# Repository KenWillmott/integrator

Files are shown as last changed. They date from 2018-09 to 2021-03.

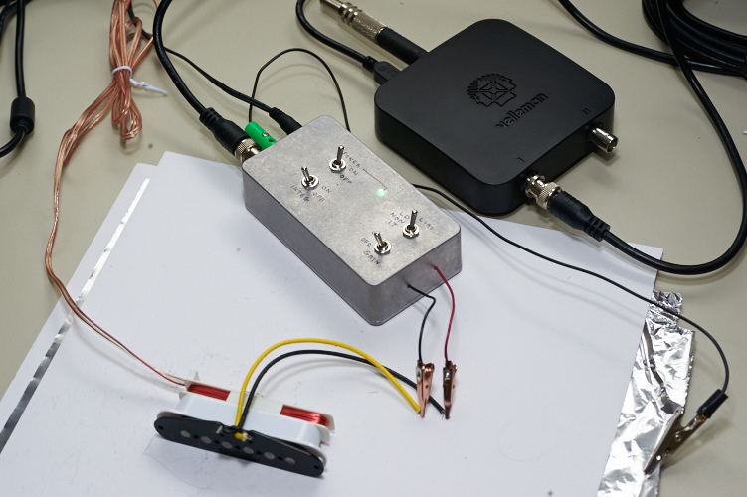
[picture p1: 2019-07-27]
CIN_1659.jpg

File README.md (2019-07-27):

# integrator
Guitar pickup test instrument

The V5.8 integrator circuit provides a high impedance preamplifier, an integrator, and an output amplifier. It also has switches to control input gain, and to select between internally provided test loads. One of the loads is a large capacitor, to measure inductance, and the other is an RC load to simulate a typical guitar circuit. A three way switch can select between these two loads, or neither load in order to make an unloaded (actually minimally loaded) measurement.

For more details, read the wiki:
https://github.com/KenWillmott/integrator/wiki

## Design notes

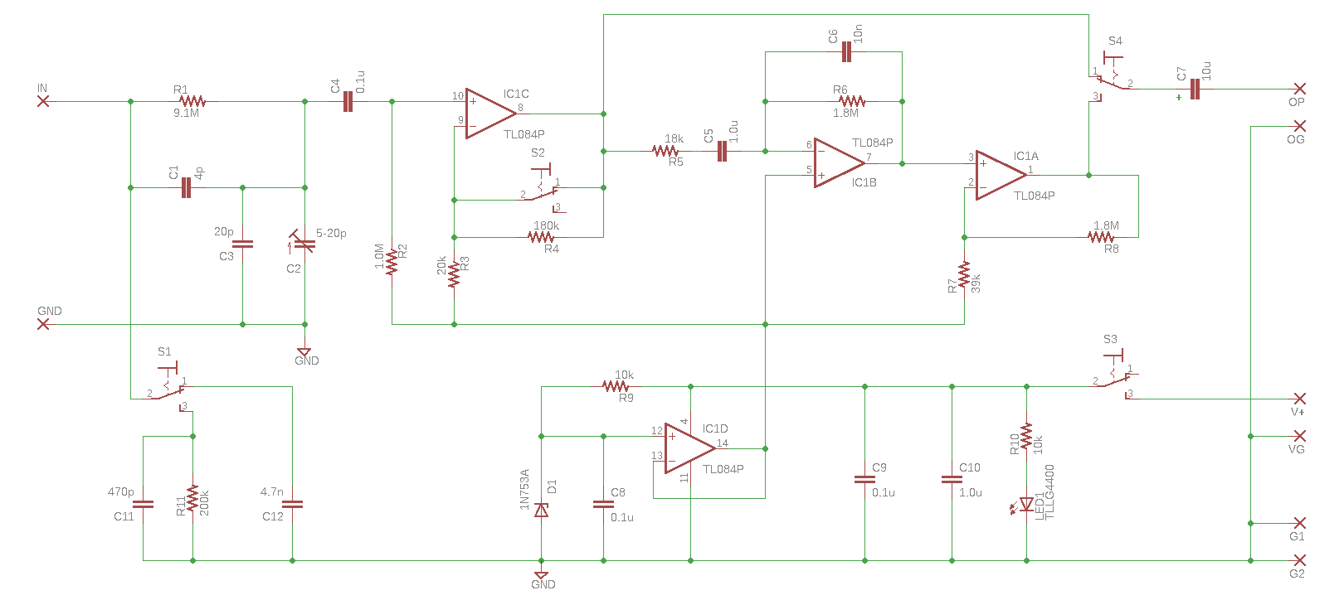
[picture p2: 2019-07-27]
board_V5.8-schematic.png

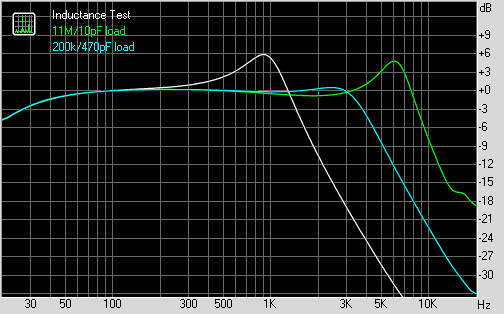
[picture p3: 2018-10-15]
Spectrum.png

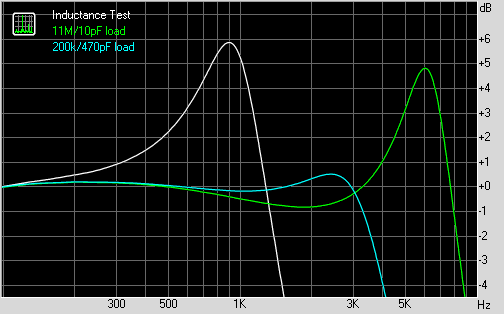
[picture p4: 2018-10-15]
Spectrum_detail.png

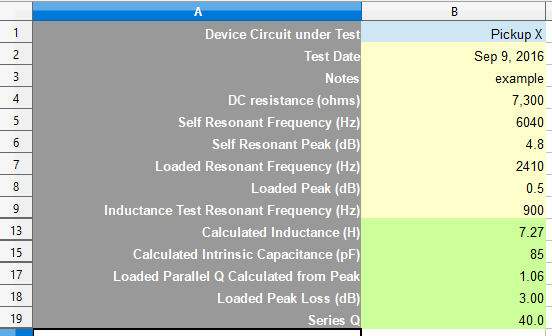
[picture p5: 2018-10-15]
spreadsheet.png

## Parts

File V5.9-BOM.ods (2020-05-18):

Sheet: PCB
Designation | Value | Description | Part Markings | Part # | Manufacturer | Supplier | Supplier Part # | Cost per Unit (CAN$) | Notes
IC1 |  | JFET op amp |  | LT1058ACN | Linear Technology | Mouser | 584-LT1058CN#PBF | $11.91 | Substitutes: LT1058CN/OP482/LF347B/TL084
D1 | 6.2V/500mW | Zener diode |  | 1N753A | Central Semiconductor | Mouser | 610-1N753A | $0.59
LED1 |  | LED |  | LTL-4231N | Lite-On | Mouser | 859-LTL-4231N | $0.10 | 3mm
S1 | On-off-on | toggle switch |  | 100SP3T1B1M2QEH | E-switch | Mouser | 612-100-C1121 | $4.06
S2 | On-on | toggle switch |  | 100SP1T1B1M2QEH | E-switch | Mouser | 612-100-A1121 | $3.37
S3 | On-on | toggle switch |  | 100SP1T1B1M2QEH | E-switch | Mouser | 612-100-A1121 | $3.37
S4 | On-on | toggle switch |  | 100SP1T1B1M2QEH | E-switch | Mouser | 612-100-A1121 | $3.37
R2 | 1.0M | 1/4W resistor 5% |  | CFR-25JR-52-1M | Yageo | Mouser | 603-CFR-25JR-52-1M | $0.14
R6 | 1.8M | 1/4W resistor 5% |  | CFR-25JB-52-1M8 | Yageo | Mouser | 603-CFR-25JB-52-1M8 | $0.14
R8 | 1.8M | 1/4W resistor 5% |  | CFR-25JB-52-1M8 | Yageo | Mouser | 603-CFR-25JB-52-1M8 | $0.14
R9 | 10k | 1/4W resistor 5% |  | CFR-25JB-52-10K | Yageo | Mouser | 603-CFR-25JB-52-10K | $0.14
R10 | 10k | 1/4W resistor 5% |  | CFR-25JB-52-10K | Yageo | Mouser | 603-CFR-25JR-52-10K | $0.14
R1 | 9.1M | 1/4W resistor 5% |  | CFR-25JB-52-9M1 | Yageo | Mouser | 603-CFR-25JB-52-9M1 | $0.14
R4 | 180k | 1/4W resistor 5% |  | CFR-25JB-52-180K | Yageo | Mouser | 603-CFR-25JB-52-180K | $0.14
R5 | 18k | 1/4W resistor 5% |  | CFS1/4CT52R183J | Koa Speer | Mouser | 660-CFS1/4CT52R183J | $0.24
R11 | 200k | 1/4W resistor 5% |  | CFR-25JB-52-200K | Yageo | Mouser | 603-CFR-25JB-52-200K | $0.14
R3 | 20k | 1/4W resistor 5% |  | CFR-25JB-52-20K | Yageo | Mouser | 603-CFR-25JB-52-20K | $0.14
R7 | 39k | 1/4W resistor 5% |  | CFR-25JR-52-39K | Yageo | Mouser | 603-CFR-25JR-52-39K | $0.14
C6 | 10n | MLCC capacitor | 103 | SR155C103JAA | AVX | Mouser | 581-SR155C103JAA | $0.65 | 50V 5%
C4 | 0.1u | MLCC capacitor | 104 | SR215C104JARTR1 | AVX | Mouser | 581-SR215C104JARTR1 | $0.47 | 50V 5%
C8 | 0.1u | MLCC capacitor | 104 | SR215C104JARTR1 | AVX | Mouser | 581-SR215C104JARTR1 | $0.47 | 50V 5%
C9 | 0.1u | MLCC capacitor | 104 | SR215C104JARTR1 | AVX | Mouser | 581-SR215C104JARTR1 | $0.47 | 50V 5%
C5 | 1u | MLCC capacitor | 105 | C330C105J5R5TA | Kemet | Mouser | 80-C330C105J5R | $2.32 | 50V 5%
C7 | 10u | MLCC capacitor | 106 | SR655C106KARTR1 | AVX | Mouser | 581-SR655C106KARTR1 | $6.01 | 50V 5%
C10 | 10u | MLCC capacitor | 106 | C330C105J5R5TA | Kemet | Mouser | 80-C330C105J5R | $2.32 | 50V 5%
C3 | 20p | MLCC capacitor | 200 | SR211A200JAR | AVX | Mouser | 581-SR211A200JAR | $0.51 | 100V 5%
C11 | 470p | MLCC capacitor | 471 | SR215A471JARTR1 | AVX | Mouser | 581-SR215A471JARTR1 | $0.44 | 50V 5%
C12 | 4.7n | MLCC capacitor | 472 | SR215C472JARTR1 | AVX | Mouser | 581-SR215C472JARTR1 | $0.47 | 50V 5%
C1 | 4p | MLCC capacitor | 4 | RDE5C1H4R0C0S1H03A | Murata | Mouser | 81-RDE5C1H4R0C0S1H3A | $0.50 | 50V
C2 | 5-20p | trimmer capacitor |  | GKG20015 | Sprague-Goodman | Mouser | 659-GKG20015 | $6.07 | 6mm
 |  |  |  |  |  |  | (total CAN$) | $49.11

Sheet: Unit
Description | Part # | Manufacturer | Supplier | Supplier Part # | Cost per Unit (CAN$) | Notes
Housing | 1590B | Hammond | Mouser | 546-1590B | $10.36 | Use 1590BBK/Mouser 546-1590B-BK for black housing
DC jack |  |  |  |  |  | 2.1mm DC power jack
banana jack |  |  |  |  |  | small jack for auxiliary ground
BNC panel jack |  |  |  |  |  | for signal output

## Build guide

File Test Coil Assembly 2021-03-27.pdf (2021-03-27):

# Pickup Test Coil Assembly

## Ken Willmott 2021-03

Description
This coil is used to induce a signal in a guitar pickup for the purposes of measuring the pickup frequency response characteristics. It is designed to be driven by a signal generator or audio interface headphone output, and placed in close proximity to the pickup face in order to induce a signal in the pickup by magnetic induction. The magnetic field that the coil produces emulates the time varying magnetic field that the guitar strings produce when they vibrate in front of the pickup.
This is the most common type of pickup test coil, where the test field encompasses the entire pickup. It is also possible to use smaller coils in order to measure a smaller area of the pickup assembly. Experiments have shown that, when used properly, it has minimal effect on the pickup’s response due to its proximity to the pickup’s electromagnetic circuits.
Guitar pickups work by magnetic induction of electrical currents in the pickup coil when a time varying magnetic field is applied (normally, from the strings). This means that every pickup follows, at least closely, Faraday’s Law of Induction which results in the output signal increasing by 6dB/octave or 20dB/decade as the frequency increases. This is the natural mode of signal production in an electric guitar, and produces its characteristic sound.
However, this aggregate response is not ideal for analysis of the important pickup characteristics that derive from the electrical response of the pickup components alone. For this reason, an integrator circuit is normally also required to apply an inverse response of -6db/octave or -20dB/decade, to compensate for the increasing slope produced by magnetic induction. The V5.9 integrator device can be used for this purpose. Some testing can be performed using only a test coil, with the pickup connected to an audio test device through a resistor network.
To produce an accurate plot of output versus frequency, the magnetic field intensity must be constant regardless of frequency. The magnetic field intensity of a coil is proportional to applied current. Since the coil is an inductor electrically, a constant applied voltage would not produce a uniform current at different frequencies. So, it is necessary to incorporate some kind of current regulation in the coil, since the signal generator is generally a voltage source. A series resistance will work for this, if the reactive impedance of the coil is much smaller than its resistance at the highest test frequency used. It is helpful to keep the coil inductance value low in order to achieve this. Most signal generators and also headphone outputs already have an internal resistance that can provide this function if the coil inductance is low enough, thus it may be possible to connect a coil directly. However, I include a 100 ohm resistor in the circuit to ensure that there is an adequate margin regardless of what device is driving the coil.

Specifications

Parameter | Value | Units
Typical drive level | 1 | Vrms
Maximum drive level | 5 | Vrms
Coil inductance | 100 | uH
DC resistance | 100 | ohms

Materials
- Humbucker bobbin
- AWG# 30 magnet wire
- 1-7/8” Kapton tape
- 1/2” Kapton tape
- 36” AWG# 26 stranded insulated 2 conductor wire
- 100 ohm 1/2W axial lead resistor
- 3/4” heat shrink tubing

Tools
- Wire cutter
- Soldering iron
- 1/16” drill bit
- hand drill or drill press

Procedure
Follow the steps illustrated in the following images. The coil winding itself is not shown, but it consists of securing the bobbin to a handle or bench jig, and applying turns by hand. A motorized method could be used but the turns can be applied by hand in just a few minutes.
Pay attention to soldering technique, ensure that there are no shorts or cold solder joints. The side opposite to the side that carries the components, should be kept as flat as possible when the tape is wrapped around the bobbin. That is so it will remain in a fixed, stable position when it is used on the top of a single coil type pickup.

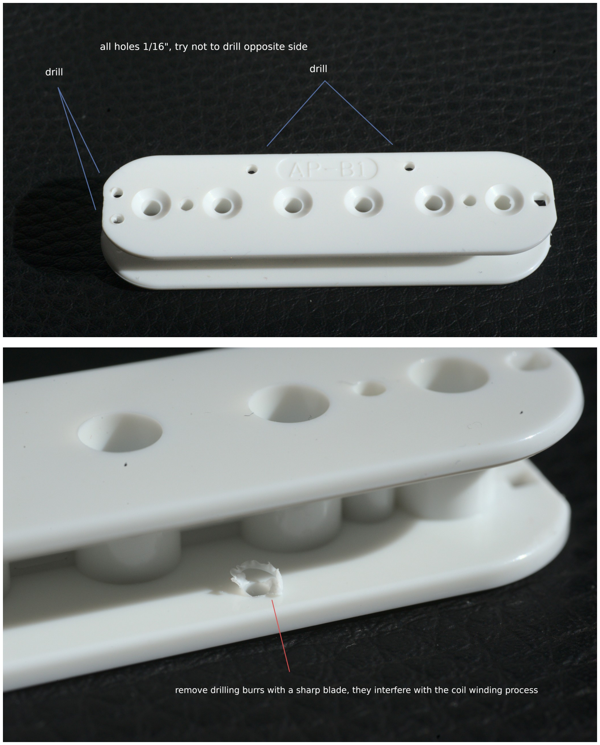
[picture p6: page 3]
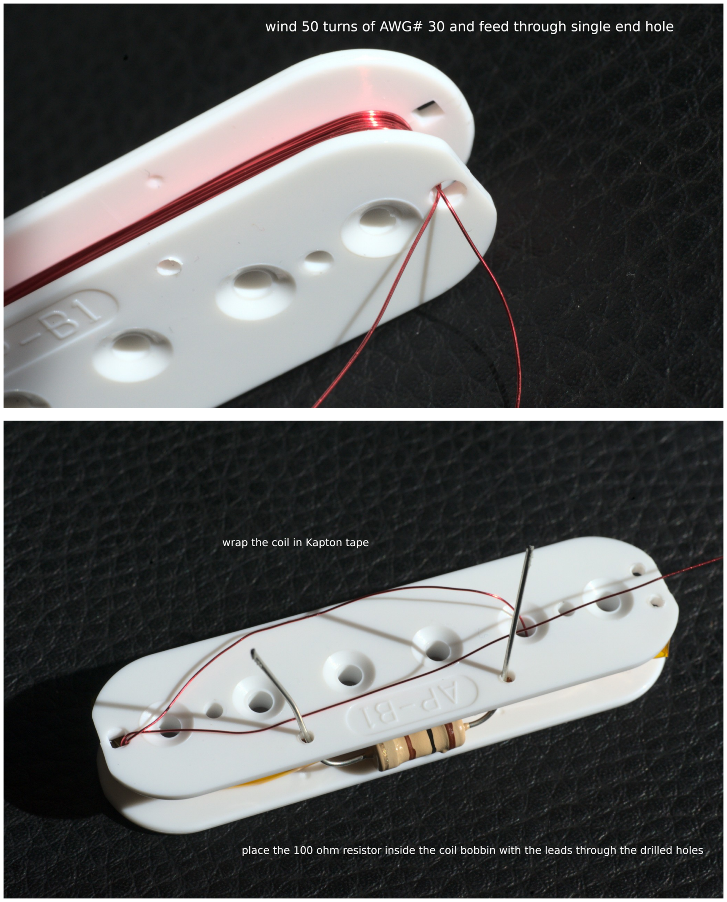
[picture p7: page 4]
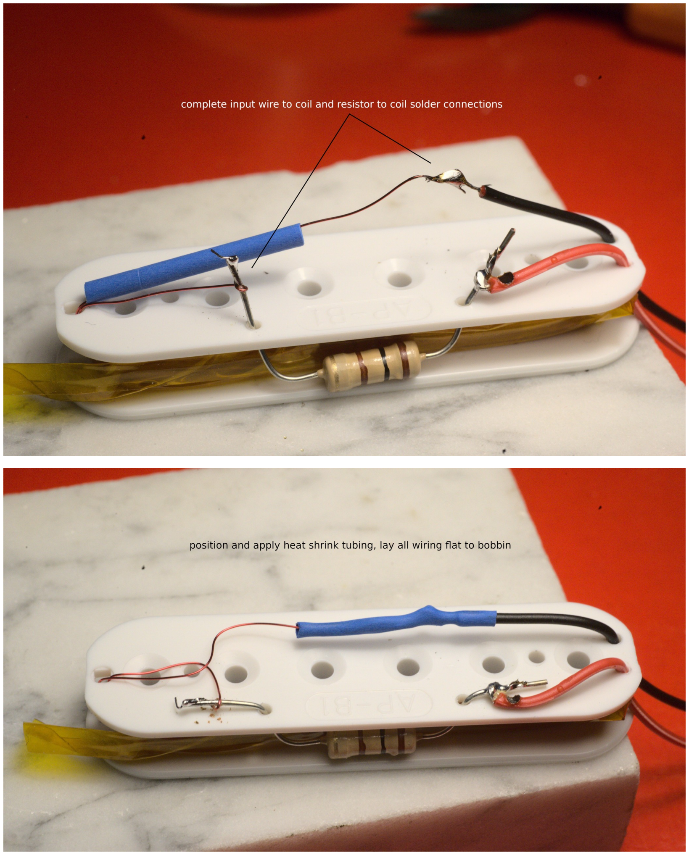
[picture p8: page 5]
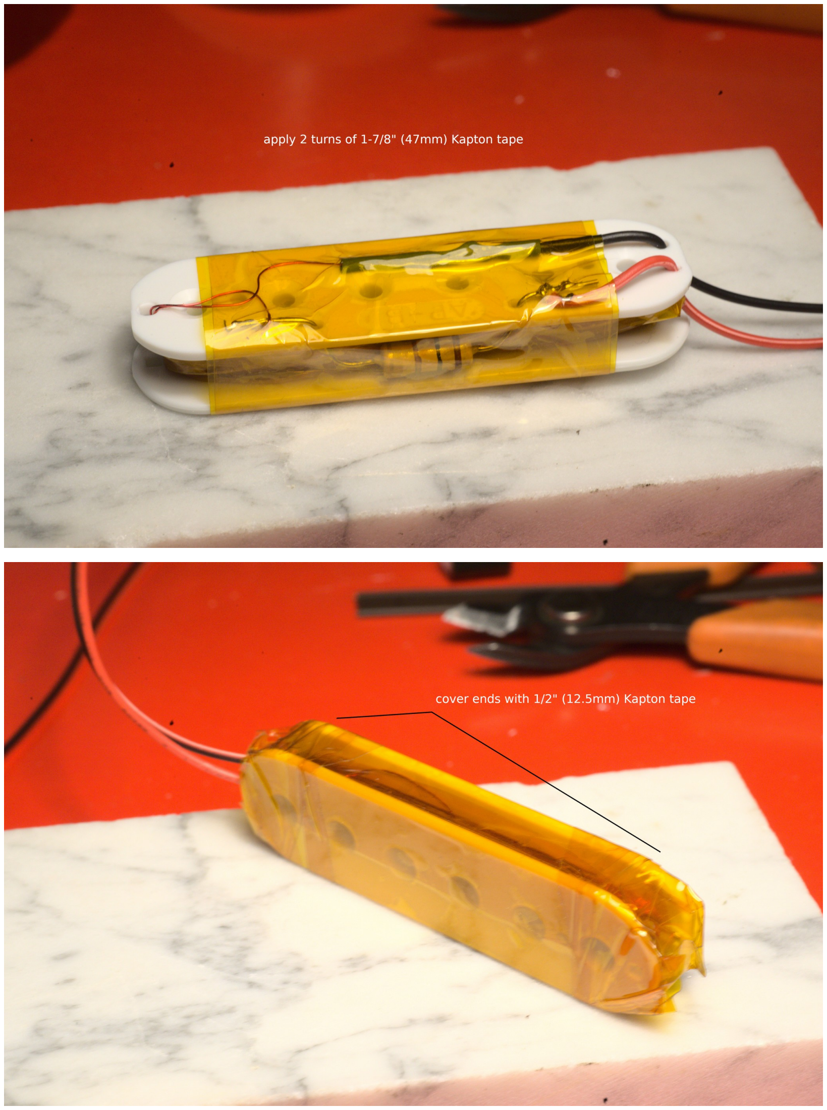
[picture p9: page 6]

References
https://github.com/KenWillmott/integrator/wiki

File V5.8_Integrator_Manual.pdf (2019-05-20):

# V5.8 Integrator Manual

This document explains how to produce the Bode plots for an electromagnetic guitar pickup using the V5.8 Integrator.

Equipment:

- Test coil – 50-100 turns of 26 AWG coated copper magnet wire on a non-magnetic bobbin such as plastic or wood.
- V5.8 integrator board
- Either one of these:
1. computer audio interface such as the Scarlett Focusrite 2i2 or equivalent
2. software oscilloscope
- RightMark audio test software or equivalent

Overview:

The test setup consists of an audio signal loop, where signals produced by the test software suite are sent from the output of the computer interface device, to the test coil. The field from the test coil induces a voltage in the pickup, which is connected to the input of the integrator. The integrator output is connected to the input of the audio device, where it is converted to digital format and returned to the audio test software suite for recording and analysis.

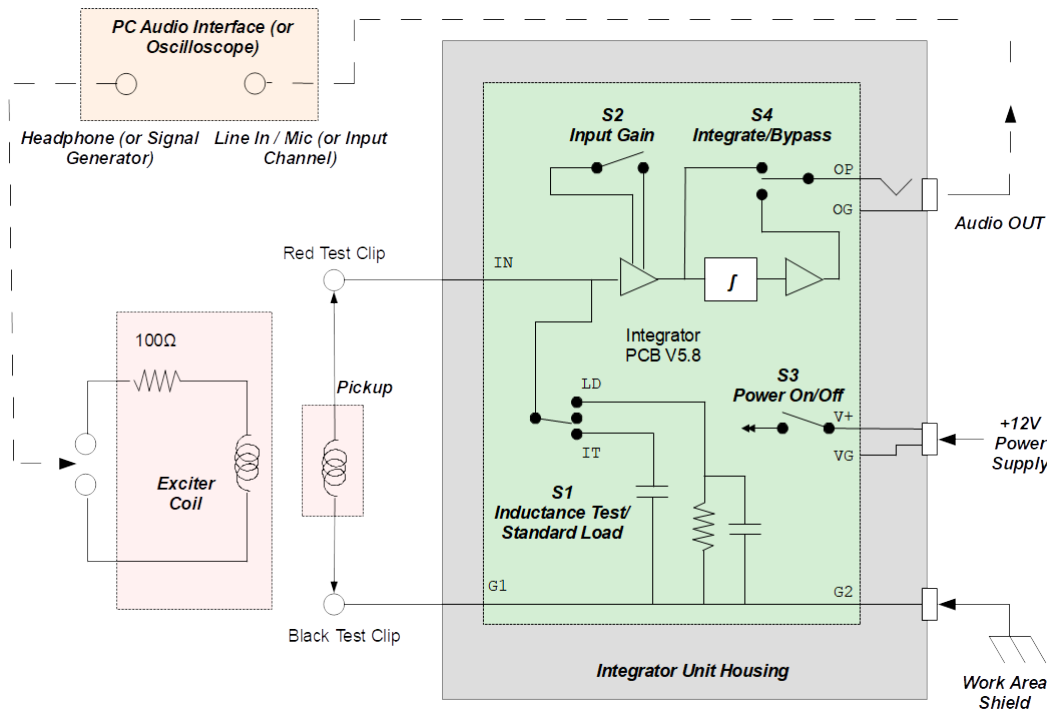
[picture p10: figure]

Here is a photograph of a typical test bench layout:

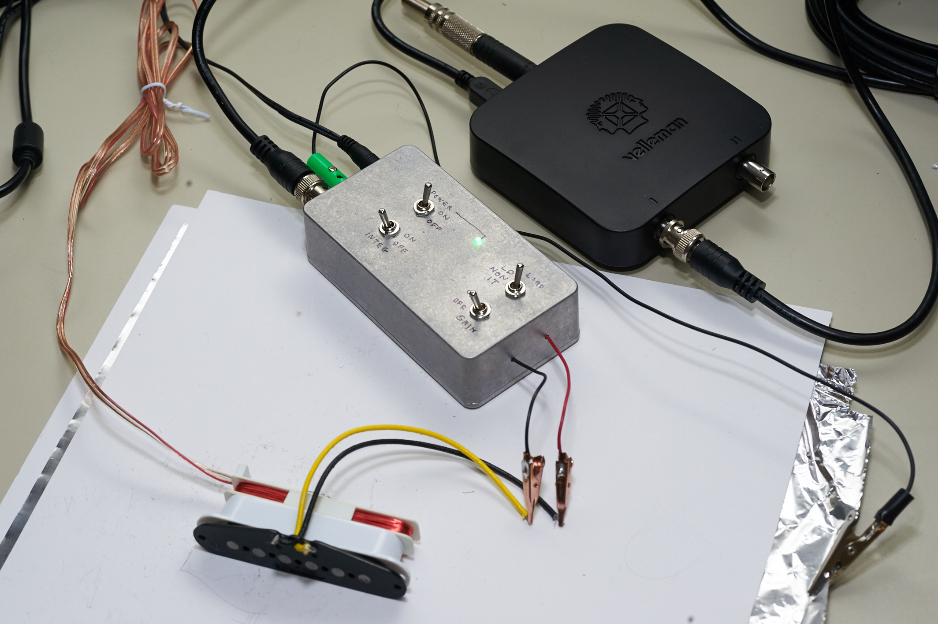
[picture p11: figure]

The V5.8 integrator circuit provides a high impedance preamplifier, an integrator, and an output amplifier. It also has terminals for switches to control input gain, and to select between internally provided test loads. One of the loads is a relatively large capacitor, to measure inductance, and the other is an RC load to simulate a typical guitar circuit. A three way switch can select between these two loads, or neither load in order to make an unloaded (actually minimally loaded) measurement. An auxiliary ground wire connects to a workbench shield (not shown). In the photo above, it is a large piece of aluminum foil underneath the paper surface that supports the test apparatus. This is for hum reduction.

To prepare for the test, the test coil must be placed against the pickup housing. The leads are connected to the integrator input. If the pickup is shielded, the shield connection should also be connected to the input ground (black). Connecting IN to the shield will result in bad measurements. Otherwise the polarity does not matter. Ensure that 12V power is applied to the integrator and that connections to and from the computer interface are complete. Launch the software suite and configure the sound interface options, select the option to perform Bode plots, and any other settings that are permanently required. Ensure that any monitor loopback setting in the audio device is disabled.

Procedure:

Launch the analysis software suite. For RightMark, you can click on a "Run Tests" button. It will show you the following display, if no pickup is connected:

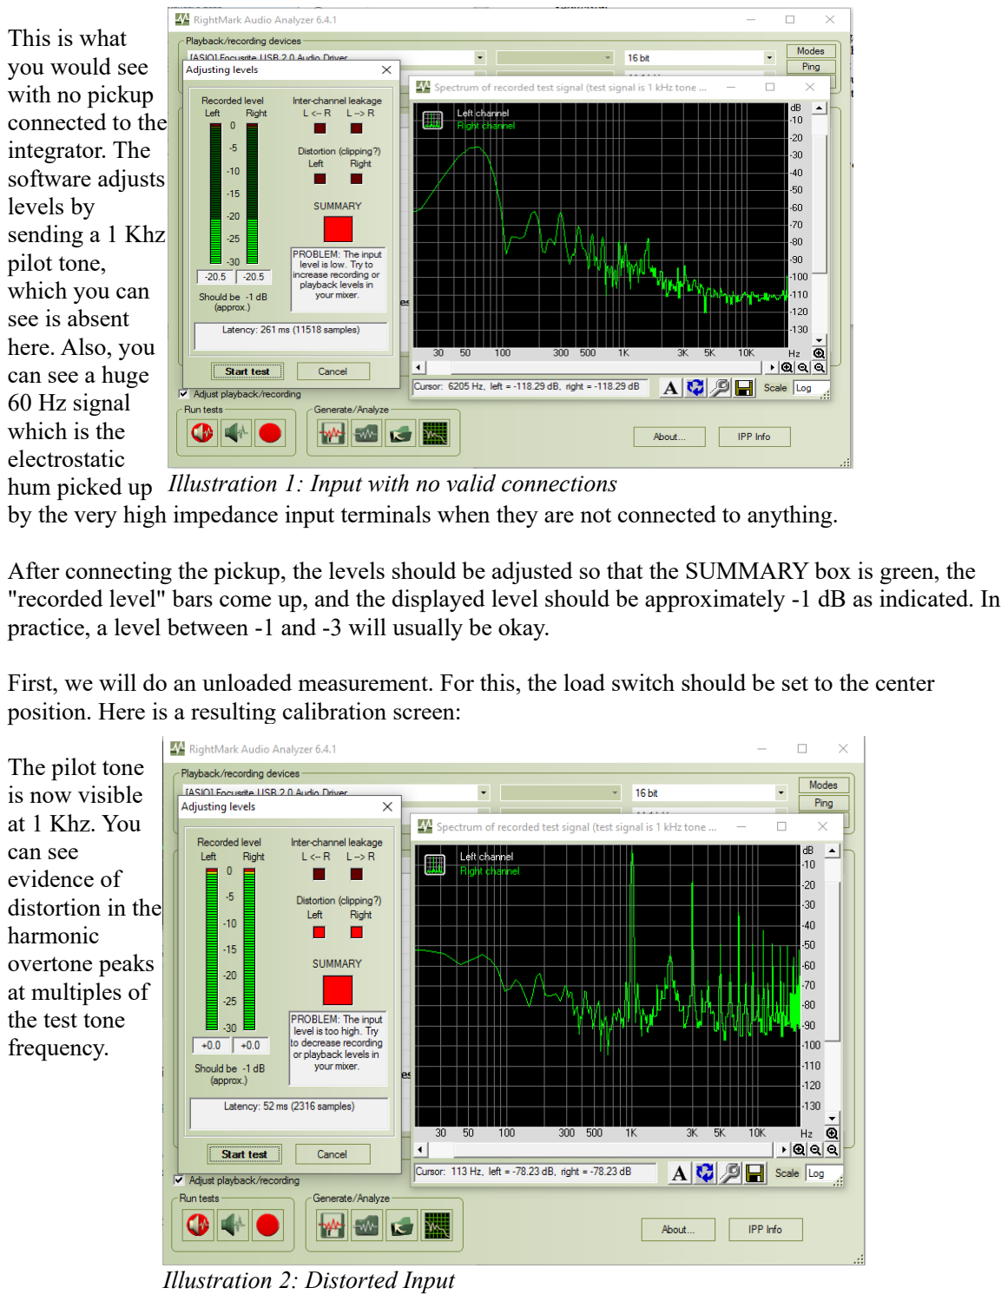
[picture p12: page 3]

This is what
you would see
with no pickup
connected to the
integrator. The
software adjusts
levels by
sending a 1 Khz
pilot tone,
which you can
see is absent
here. Also, you
can see a huge
60 Hz signal
which is the
electrostatic
hum picked up
by the very high impedance input terminals when they are not connected to anything.

After connecting the pickup, the levels should be adjusted so that the SUMMARY box is green, the "recorded level" bars come up, and the displayed level should be approximately -1 dB as indicated. In practice, a level between -1 and -3 will usually be okay.

First, we will do an unloaded measurement. For this, the load switch should be set to the center position. Here is a resulting calibration screen:

The pilot tone
is now visible
at 1 Khz. You
can see
evidence of
distortion in the
harmonic
overtone peaks
at multiples of
the test tone
frequency.

Illustration 1: Input with no valid connections

Illustration 2: Distorted Input

To obtain the best signal to noise, it is good to increase the drive to the test coil as much as possible, and then adjust the audio interface input level until the right level is attained, and there is not too much distortion or 60 Hz interference as it appears in the previous two illustrations. As a rule of thumb, neither the distortion products, nor the hum, should exceed -50 dB or so. It is possible to run tests with greater than this, but the accuracy will be impaired.

Here is a good calibration screen, when you see this you can press the "Start Test" button:

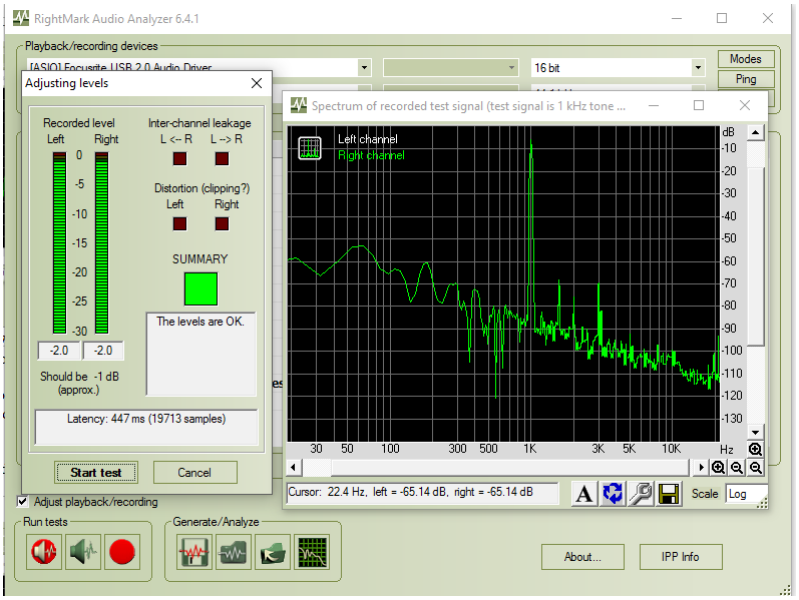
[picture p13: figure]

When the frequency sweep is completed, you will be prompted to save the plot. It is a good idea to name it at this point by typing in the name field. In this case, I'm calling it "No load".

Illustration 3: Typical acceptable calibration screen

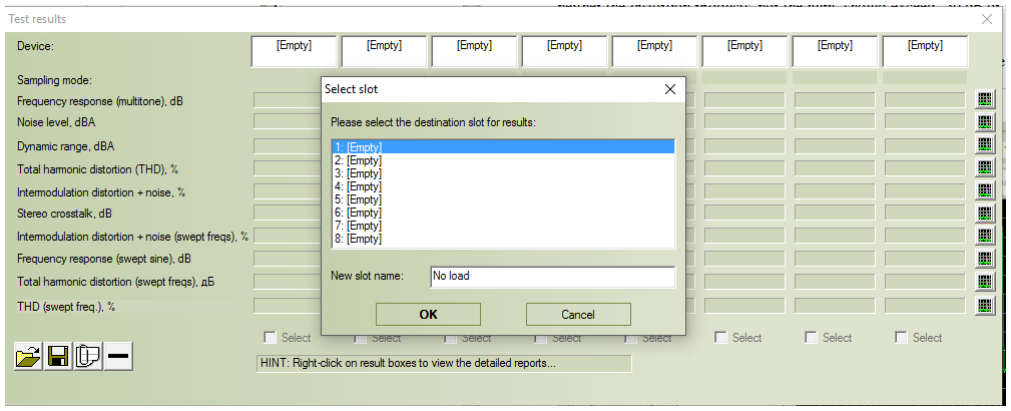
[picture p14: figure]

Click on "OK". Now your first sweep will be recorded in the first of 8 possible slots:

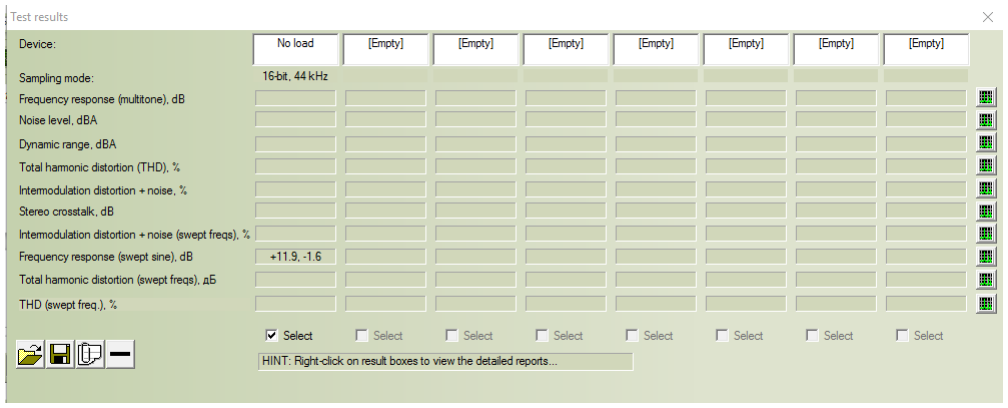
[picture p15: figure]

Move the load select switch on the integrator to the "test load" position. Click again on the "Run Tests" button. Adjust the levels as before, and complete another sweep. You will again be prompted and you can name this sweep "loaded" for example (You can also include the pickup name or any data you want to appear on the final plot).

Finally, Move the load select switch on the integrator to the "Inductance test" position. Click again on the "Run Tests" button. After running and naming the sweeps, you will now have three sweeps stored:

Illustration 4: Name the slot

Illustration 5: First slot

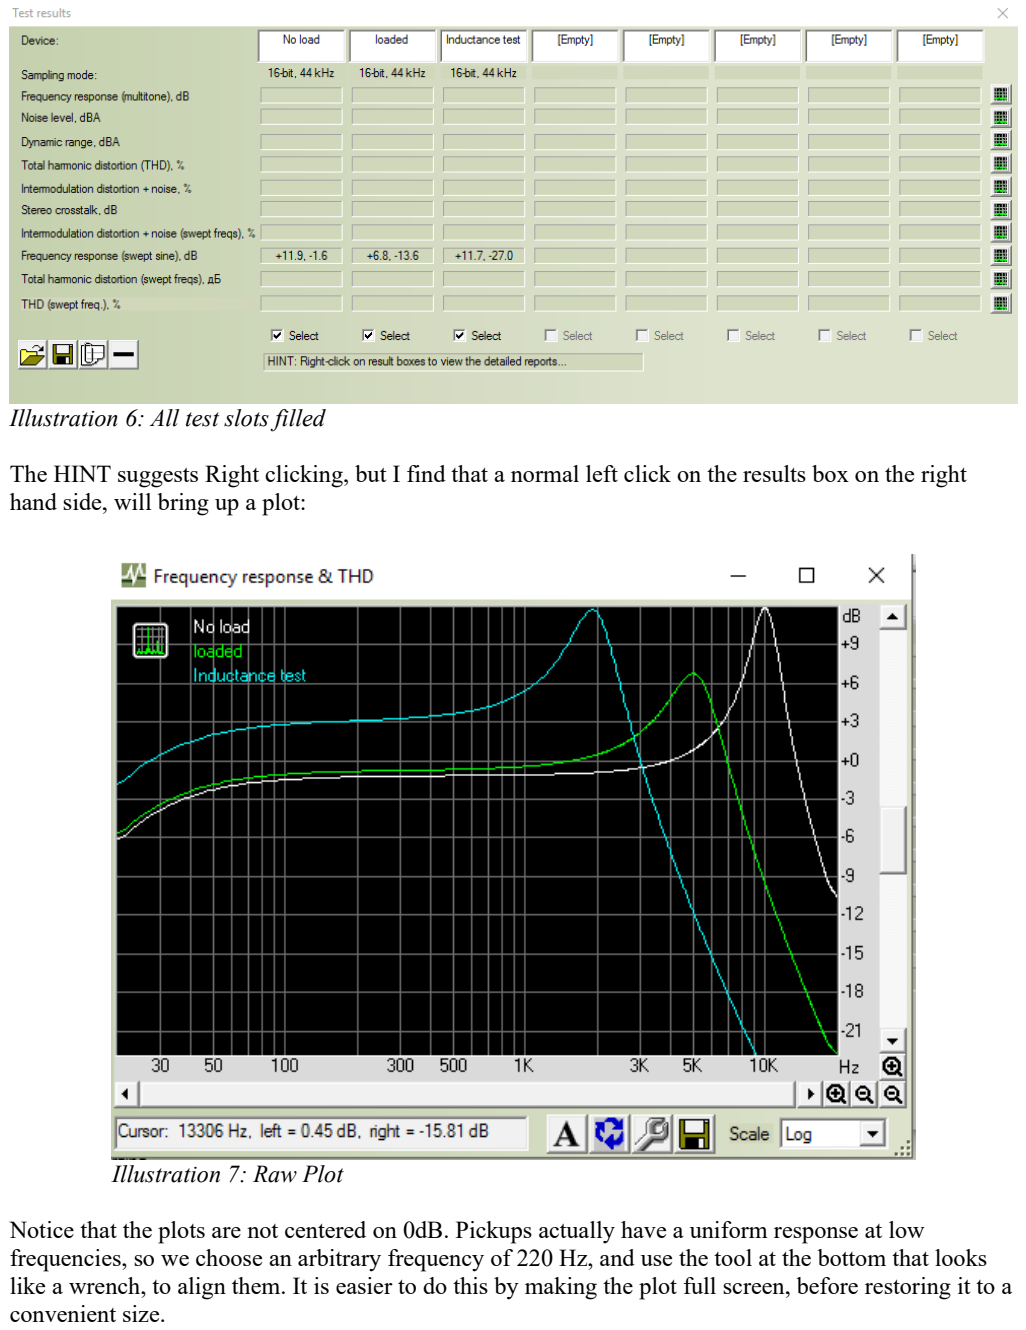
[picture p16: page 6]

The HINT suggests Right clicking, but I find that a normal left click on the results box on the right hand side, will bring up a plot:

Notice that the plots are not centered on 0dB. Pickups actually have a uniform response at low frequencies, so we choose an arbitrary frequency of 220 Hz, and use the tool at the bottom that looks like a wrench, to align them. It is easier to do this by making the plot full screen, before restoring it to a convenient size.

Illustration 6: All test slots filled

Illustration 7: Raw Plot

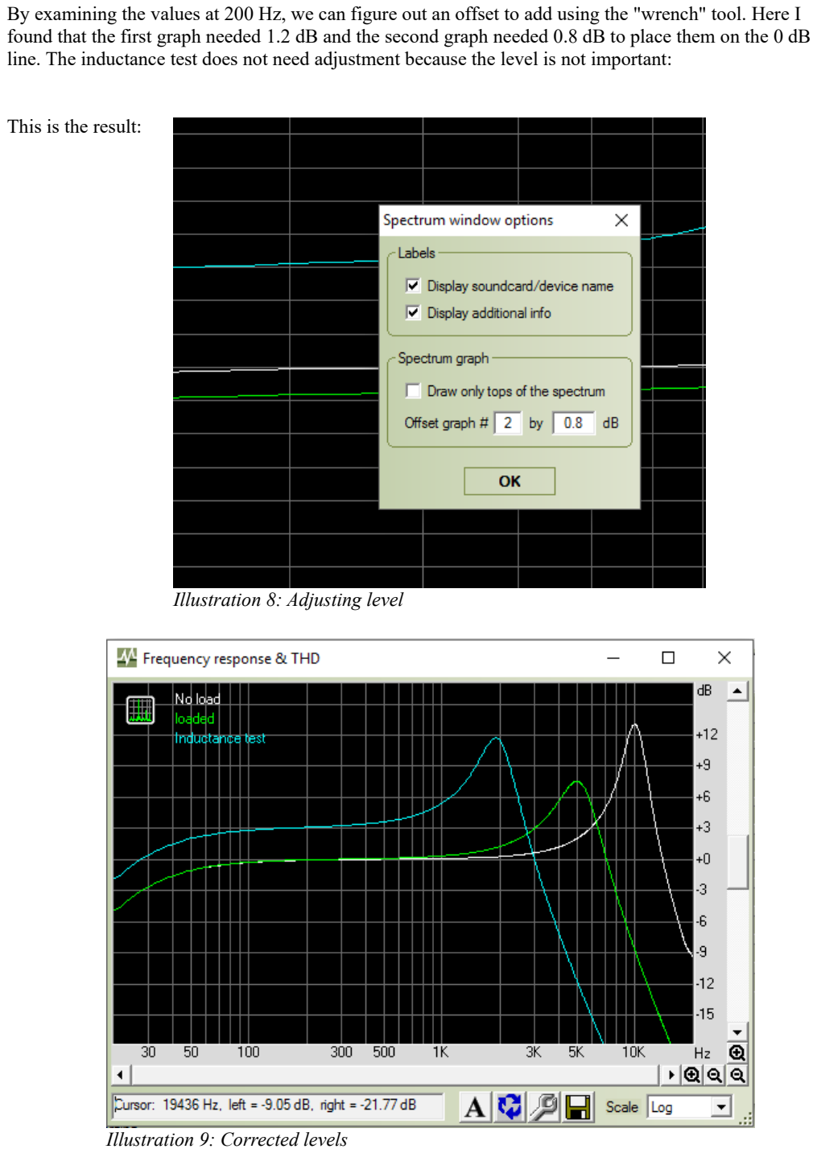
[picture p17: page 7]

By examining the values at 200 Hz, we can figure out an offset to add using the "wrench" tool. Here I found that the first graph needed 1.2 dB and the second graph needed 0.8 dB to place them on the 0 dB line. The inductance test does not need adjustment because the level is not important:

This is the result:

Illustration 8: Adjusting level

Illustration 9: Corrected levels

Now that the levels are corrected, we can use the zoom tools in Rightmark to collect data. Here we place the cursor on the peak of the unloaded measurement, and the frequency is displayed in a text box at the lower left, as well as it being possible to read with reference to the marking grid.

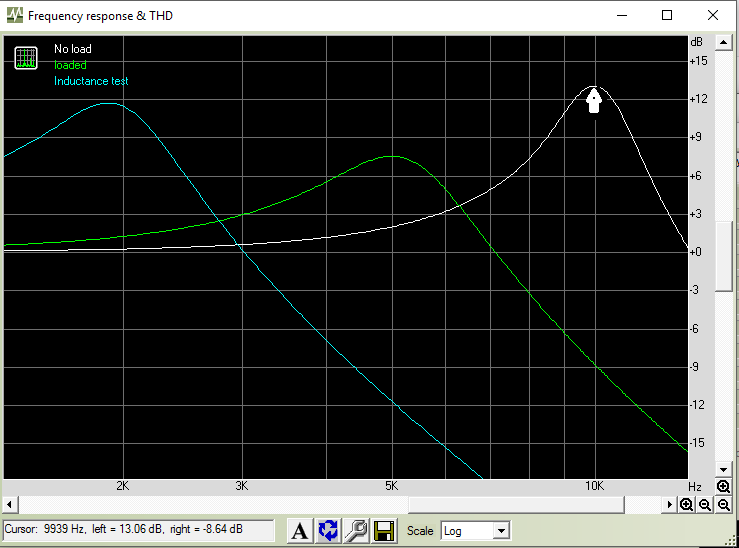
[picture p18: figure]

After the peak amplitude and frequency of the loaded and unloaded plots, and the frequency of the inductance test are recorded, the plots can be selected and scaled in various ways to highlight different aspects or display a useful overall graph. With eight slots available, more than one pickup can be compared with another, or changes in the pickup can be documented. I have found that it is useful to have a spreadsheet that can be used to enter the data that is produced by the plots, and automatically calculates key values, such as the inductance.

Illustration 10: Capturing measurement data

## Input Frequency Response Calibration

The input circuit consists of an RC voltage divider, as is used in most oscilliscope probes. Just as with the probes, stray capacitances in the circuit require that the capacitor values be adjusted to achieve a flat frequency response. Probes have an adjustable capacitor to allow user adjustment, and this feature is also built into the V5.8 PCB. Consequently, it is good to adjust variable capacitor C2 after constructing a new integrator. This should also be done if the op amp is replaced.
The values of C1 and C2 are chosen somewhat empirically to match the present layout and input capacitance of the LT1058 op amp, which influences the circuit. The 4pF/30pF (V5.6), 4pF/40pF (V5.7) 4pF/25-45pF (V5.8) combination comes quite close, but it isn't perfect. The difference shows up as an inaccuracy in amplitude values as measured here with an arbitrary pickup:

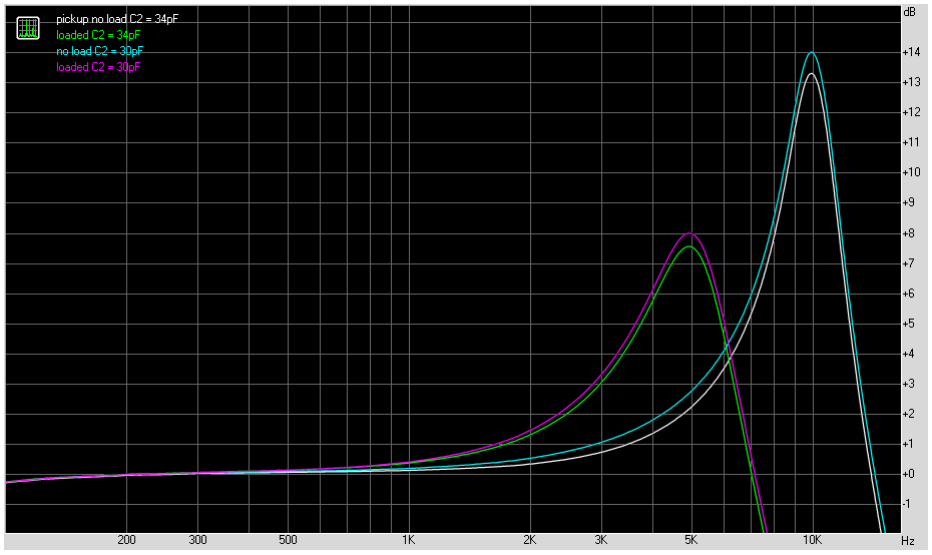
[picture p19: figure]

On an oscilloscope, the frequency response can be monitored by looking at the "squareness" of a test signal while adjusting the probe capacitor. Consequently, this method can also be used when the integrator is used with a software oscilliscope. I found another method so that the calibration can be performed without a scope, using only the integrator circuitry. The key is that the -20dB/decade slope of the integrator is combined with the input circuit slope. So, if the circuit is not balanced, a slighly different slope will be observed. By appying the sweep test generator output directly to the input, it is possible to measure and graph the integrator slope, and adjust the capacitor values until it is closer to the desired -20dB response.

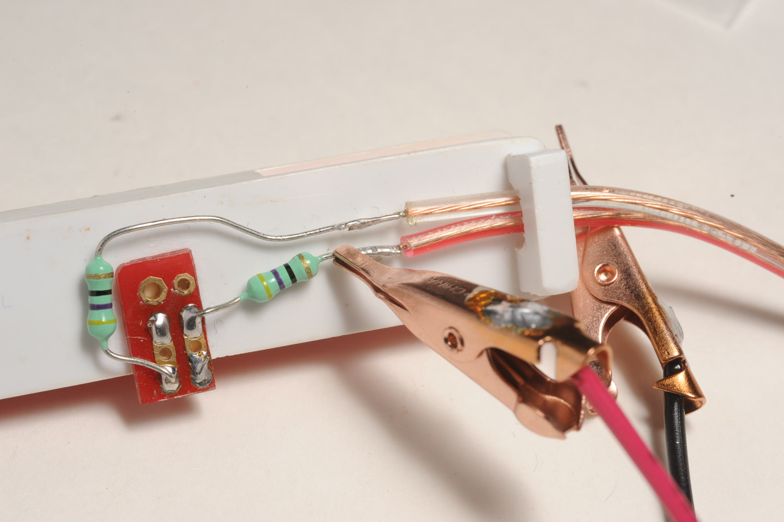
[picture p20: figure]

Since the grounds are usually common on the computer DAC interface, I found that I could just connect the input to the DAC output where it appears on the test coil (before the 100 ohm resistor!).

Running some test sweeps produces a plot that has useful slopes above 200 Hz or so. Below that, the huge gain distorts the curve but we can ignore that. By choosing two values that are a decade apart, the plot should show a -20dB difference. Choose 500 Hz as a low frequency, normalize it to 0dB and then examine the response at 5000 Hz. Adjusting variable capacitor C2 will alter the slope. Thus when the normalized response is exactly -20dB at 5000 Hz, calibration is complete.

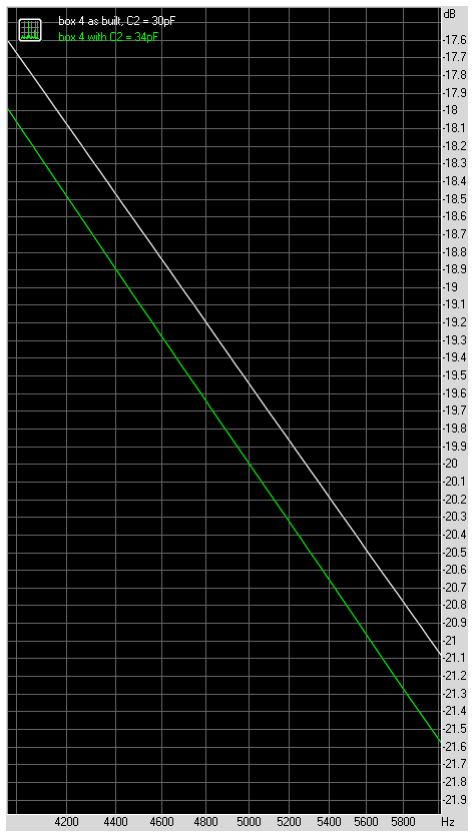
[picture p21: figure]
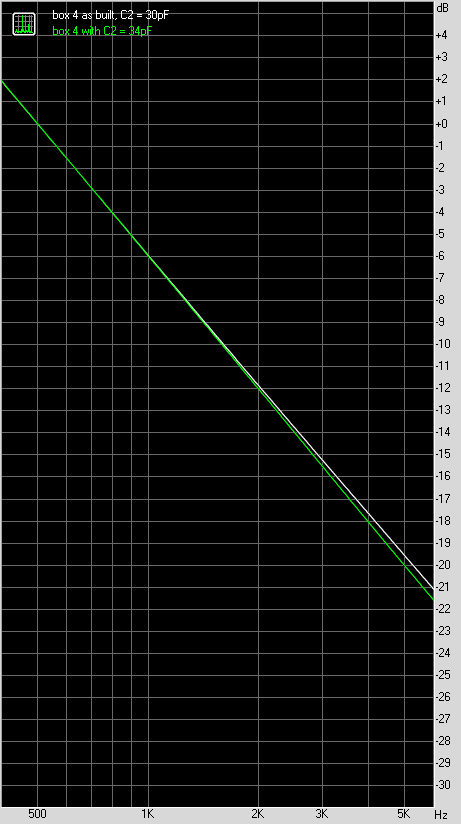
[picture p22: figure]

If an oscilloscope is available, it is much easier to adjust C2 using the traditional squarewave method. Apply an approximately 500Hz square wave from a signal generator, or from the calibration lug of the scope, if it has one, to the input of the integrator. Set the integrator to the "no load" position, Gain switch to +20dB, integration switch to "off". Connect the integrator output to a scope input.
You should see the square wave on the scope display. The leading edge will either overshoot or undershoot, as here:

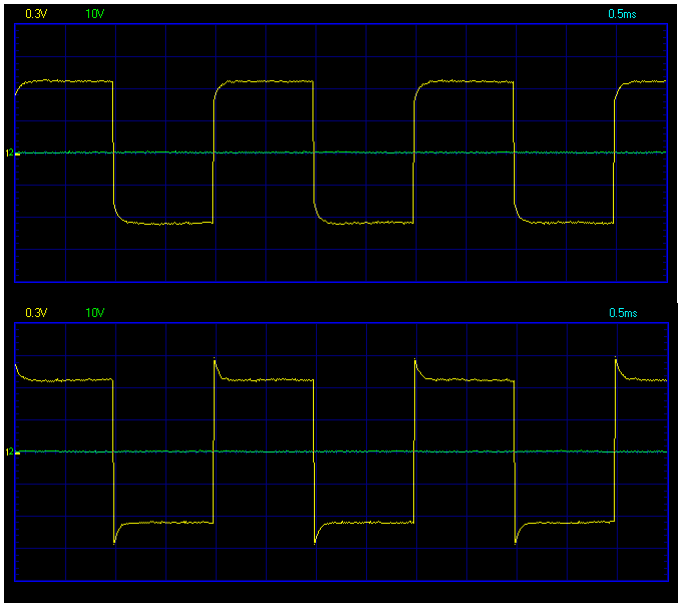
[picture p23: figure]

Simply adjust C2 until there is minimal undershoot/overshoot as below, and calibration is complete:

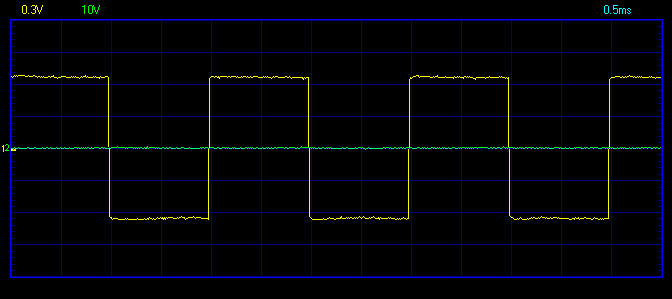
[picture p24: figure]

## Appendix

V5.8 Integrator Schematic:

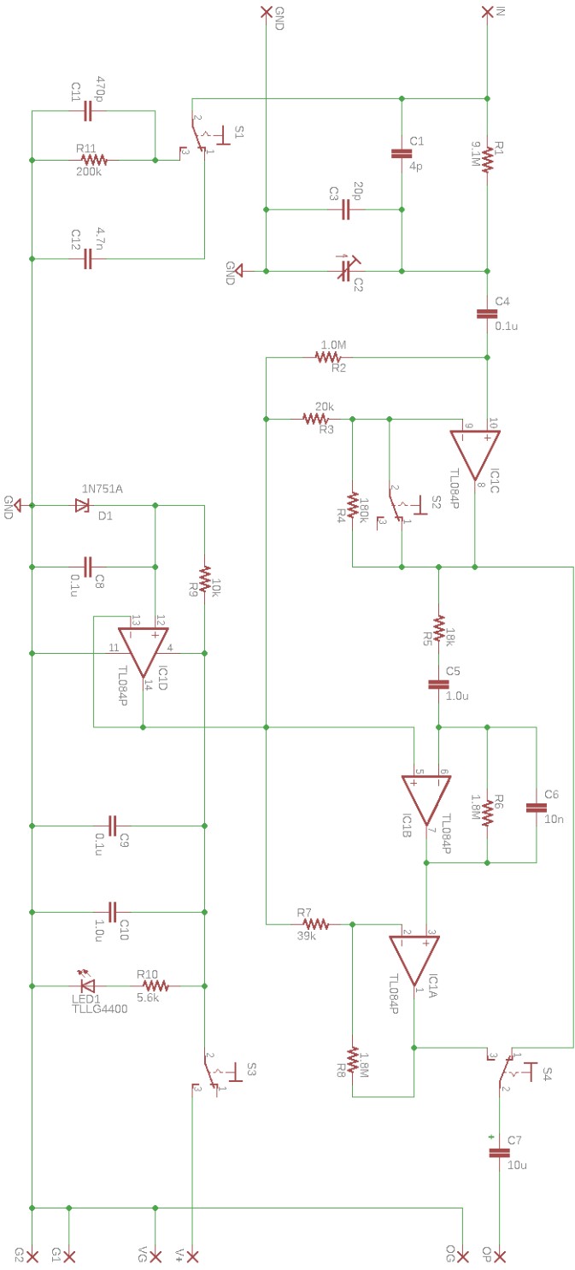
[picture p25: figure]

Note:
The schematic shows IC1 as a TL084P. This part will work, but the preferred part is the Linear Technologies LT1058ACN. The LT part has better GBP, which results in more accurate integrator response at higher frequencies.
The input circuit is sensitive, so the test leads as well as the switch connections LD/COM/IT should be as short as possible. The circuit should be in a shielded enclosure, and the test surface must be grounded. It can be conveniently connected to one of the auxiliary ground points G1/G2 by running an additional wire and clip lead for that purpose, to a banana jack on the enclosure.
Because of the sensitivity of the circuit to small capacitances, the final device calibration should be performed with the entire device fully assembled, in its case. For this reason, I recommend placing C2 on the solder side of the PCB so that it is accessible to a screwdriver with the unit assembled and the enclosure cover removed. However, I have found that the input network is mostly affected by the input components including the op amp, and does not vary significantly enough to worry about, if for some reason this is not possible.

The V5.7 circuit has been upgraded to V5.8. Here is a view of an assembled V5.8 board:

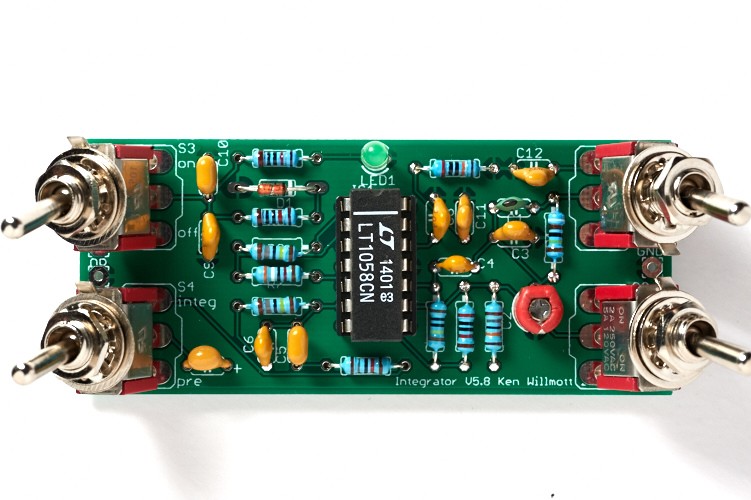
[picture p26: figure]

V5.8 Integrator PCB Parts Layout:

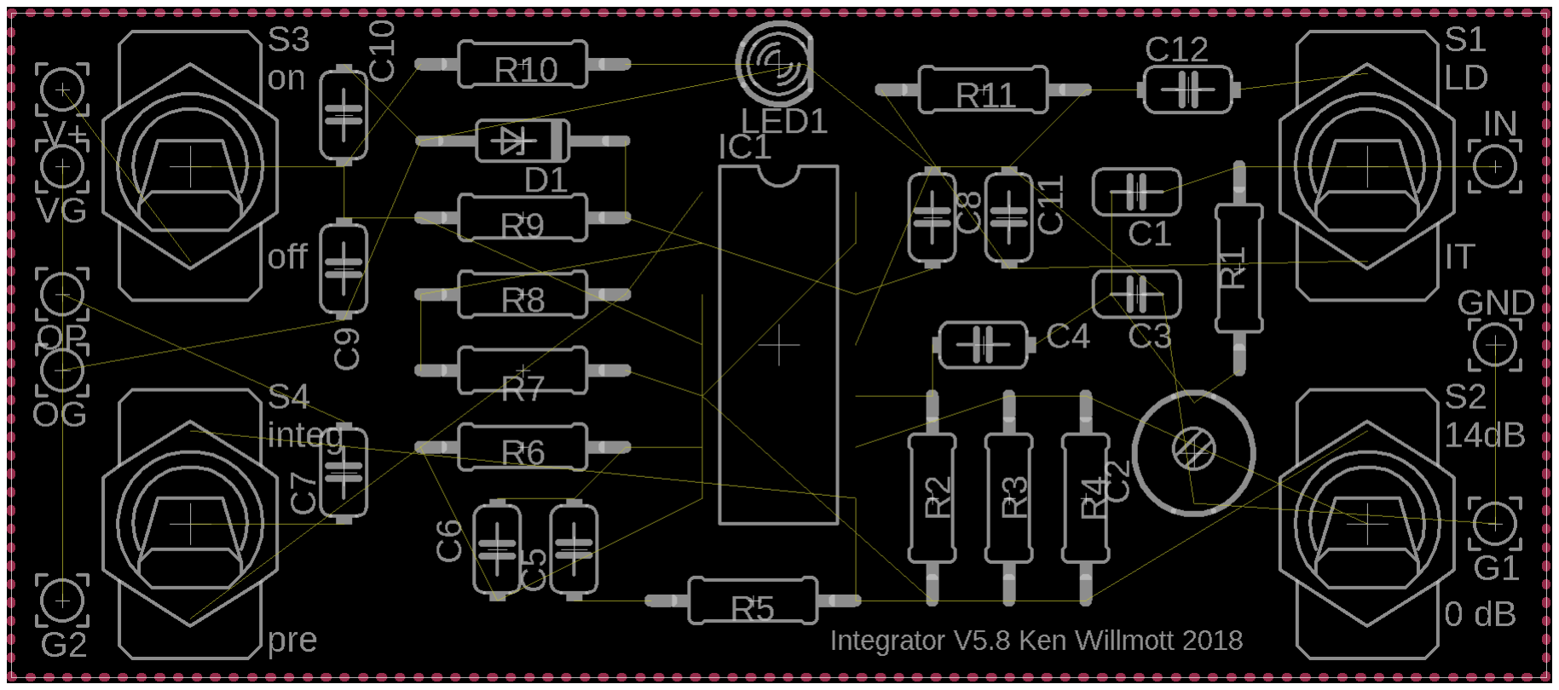
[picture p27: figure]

Here is a recommended enclosure installation:

Notes:

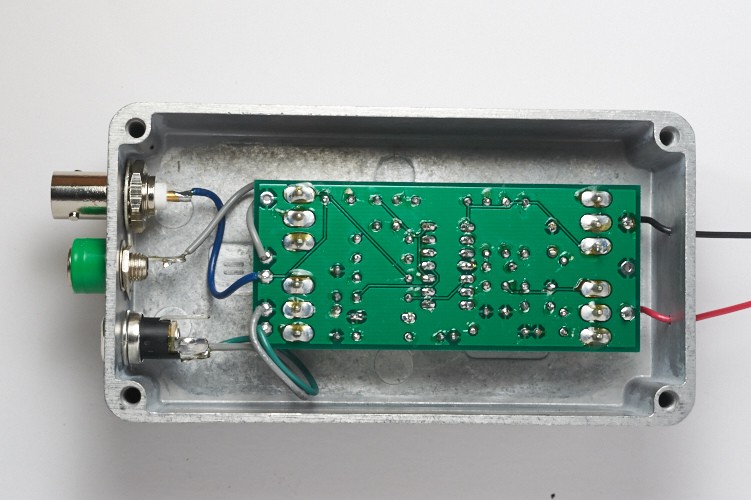
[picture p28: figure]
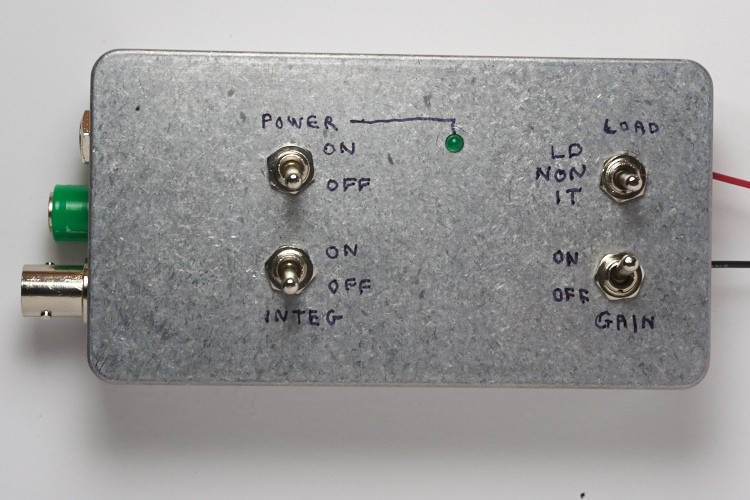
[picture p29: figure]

1. The housing is grounded via the ground connection of the output jack. This can be a BNC or 1/4" phone jack, or any other audio plug. If the jack has no ground connection to the housing, then a separate ground connection must be made to the housing, or the auxiliary ground banana jack may be used for this purpose instead.
2. The auxiliary ground connection does not normally need a wire, because it can be mounted in such a way that the sleeve contacts the housing directly, providing a ground. If needed, it can be wired to G2 on the PCB.
In order to facilitate the alignment of switch mounting holes, it is preferable to assemble the switches into the housing prior to soldering them to the PCB.

© Ken Willmott, 2019

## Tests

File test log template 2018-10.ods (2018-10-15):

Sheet: Test Log
Device Circuit under Test | Test Date | Notes | DC resistance (ohms) | Self Resonant Frequency (Hz) | Self Resonant Peak (dB) | Loaded Resonant Frequency (Hz) | Loaded Peak (dB) | Inductance Test Resonant Frequency (Hz) | Inductance Test Capacitance (F) | Probe Capacitance (pF) | Test Load Resistance (ohms) | Calculated Inductance (H) | Calculated Intrinsic Capacitance (F) | Calculated Intrinsic Capacitance (pF) | Loaded Parallel Q Calculated from Rs, Rl | Loaded Parallel Q Calculated from Peak | Loaded Peak Loss (dB) | Series Q | Calculated Loaded Resonant Frequency (Hz)
Formula template row |  |  |  |  |  |  |  |  | 4.3E-09 | 10.0 | 200,000 | #DIV/0! | #DIV/0! | #DIV/0! | #DIV/0! | 1.00 | #DIV/0! | #DIV/0! | #DIV/0!
Example Test | Sep 9, 2016 | V5.4 box | 7,300 | 6240 | 3 | 2740 | 1.4 | 1100 | 4.3E-09 | 10.0 | 200,000 | 4.87 | 1.24E-10 | 124 | 1.75 | 1.17 | 3.5 | 27.18 | 2961

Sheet: Constants
Test load resistance (ohms) | 200000
Test load capacitance (F) | 4.70E-010
Inductance test load capacitance (F) | 4.3E-09
Test probe capacitance (pF) | 10

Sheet: Results Report
Device Circuit under Test | Example Test
Test Date | Sep 9, 2016
Notes | V5.4 box
DC resistance (ohms) | 7,300
Self Resonant Frequency (Hz) | 6240
Self Resonant Peak (dB) | 3
Loaded Resonant Frequency (Hz) | 2740
Loaded Peak (dB) | 1.4
Inductance Test Resonant Frequency (Hz) | 1100
Inductance Test Capacitance (F) | 4.3E-09
Probe Capacitance (pF) | 10.0
Test Load Resistance (ohms) | 200,000
Calculated Inductance (H) | 4.87
Calculated Intrinsic Capacitance (F) | 1.24E-10
Calculated Intrinsic Capacitance (pF) | 124
Loaded Parallel Q Calculated from Rs, Rl | 2
Loaded Parallel Q Calculated from Peak | 1.17
Loaded Peak Loss (dB) | 3.53
Series Q | 27.2
Calculated Loaded Resonant Frequency (Hz) | 2960.54
Device Circuit under Test | Example Test
Test Date | 42622
Notes | V5.4 box
DC resistance (ohms) | 7300
Self Resonant Frequency (Hz) | 6240
Self Resonant Peak (dB) | 3
Loaded Resonant Frequency (Hz) | 2740
Loaded Peak (dB) | 1.35
Inductance Test Resonant Frequency (Hz) | 1100
Inductance Test Capacitance (F) | 4.3E-09
Probe Capacitance (pF) | 10
Test Load Resistance (ohms) | 200000
Calculated Inductance (H) | 4.86840205854016
Calculated Intrinsic Capacitance (F) | 1.23624054898093E-10
Calculated Intrinsic Capacitance (pF) | 123.624054898093
Loaded Parallel Q Calculated from Rs, Rl | 1.75349222989962
Loaded Parallel Q Calculated from Peak | 1.16815372986132
Loaded Peak Loss (dB) | 3.52807691539466
Series Q | 27.184344568182
Calculated Loaded Resonant Frequency (Hz) | 2960.54159609976
Device Circuit under Test | Example Test
Test Date | 42622
Notes | V5.4 box
DC resistance (ohms) | 7300
Self Resonant Frequency (Hz) | 6240
Self Resonant Peak (dB) | 3
Loaded Resonant Frequency (Hz) | 2740
Loaded Peak (dB) | 1.35
Inductance Test Resonant Frequency (Hz) | 1100
Inductance Test Capacitance (F) | 4.3E-09
Probe Capacitance (pF) | 10
Test Load Resistance (ohms) | 200000
Calculated Inductance (H) | 4.86840205854016
Calculated Intrinsic Capacitance (F) | 1.23624054898093E-10
Calculated Intrinsic Capacitance (pF) | 123.624054898093
Loaded Parallel Q Calculated from Rs, Rl | 1.75349222989962
Loaded Parallel Q Calculated from Peak | 1.16815372986132
Loaded Peak Loss (dB) | 3.52807691539466
Series Q | 27.184344568182
Calculated Loaded Resonant Frequency (Hz) | 2960.54159609976
Device Circuit under Test | Example Test
Test Date | 42622
Notes | V5.4 box
DC resistance (ohms) | 7300
Self Resonant Frequency (Hz) | 6240
Self Resonant Peak (dB) | 3
Loaded Resonant Frequency (Hz) | 2740
Loaded Peak (dB) | 1.35
Inductance Test Resonant Frequency (Hz) | 1100
Inductance Test Capacitance (F) | 4.3E-09
Probe Capacitance (pF) | 10
Test Load Resistance (ohms) | 200000
Calculated Inductance (H) | 4.86840205854016
Calculated Intrinsic Capacitance (F) | 1.23624054898093E-10
Calculated Intrinsic Capacitance (pF) | 123.624054898093
Loaded Parallel Q Calculated from Rs, Rl | 1.75349222989962
Loaded Parallel Q Calculated from Peak | 1.16815372986132
Loaded Peak Loss (dB) | 3.52807691539466
Series Q | 27.184344568182
Calculated Loaded Resonant Frequency (Hz) | 2960.54159609976
Device Circuit under Test | Example Test
Test Date | 42622
Notes | V5.4 box
DC resistance (ohms) | 7300
Self Resonant Frequency (Hz) | 6240
Self Resonant Peak (dB) | 3
Loaded Resonant Frequency (Hz) | 2740
Loaded Peak (dB) | 1.35
Inductance Test Resonant Frequency (Hz) | 1100
Inductance Test Capacitance (F) | 4.3E-09
Probe Capacitance (pF) | 10
Test Load Resistance (ohms) | 200000
Calculated Inductance (H) | 4.86840205854016
Calculated Intrinsic Capacitance (F) | 1.23624054898093E-10
Calculated Intrinsic Capacitance (pF) | 123.624054898093
Loaded Parallel Q Calculated from Rs, Rl | 1.75349222989962
Loaded Parallel Q Calculated from Peak | 1.16815372986132
Loaded Peak Loss (dB) | 3.52807691539466
Series Q | 27.184344568182
Calculated Loaded Resonant Frequency (Hz) | 2960.54159609976
Device Circuit under Test | Example Test
Test Date | 42622
Notes | V5.4 box
DC resistance (ohms) | 7300
Self Resonant Frequency (Hz) | 6240
Self Resonant Peak (dB) | 3
Loaded Resonant Frequency (Hz) | 2740
Loaded Peak (dB) | 1.35
Inductance Test Resonant Frequency (Hz) | 1100
Inductance Test Capacitance (F) | 4.3E-09
Probe Capacitance (pF) | 10
Test Load Resistance (ohms) | 200000
Calculated Inductance (H) | 4.86840205854016
Calculated Intrinsic Capacitance (F) | 1.23624054898093E-10
Calculated Intrinsic Capacitance (pF) | 123.624054898093
Loaded Parallel Q Calculated from Rs, Rl | 1.75349222989962
Loaded Parallel Q Calculated from Peak | 1.16815372986132
Loaded Peak Loss (dB) | 3.52807691539466
Series Q | 27.184344568182
Calculated Loaded Resonant Frequency (Hz) | 2960.54159609976
Device Circuit under Test | Example Test
Test Date | 42622
Notes | V5.4 box
DC resistance (ohms) | 7300
Self Resonant Frequency (Hz) | 6240
Self Resonant Peak (dB) | 3
Loaded Resonant Frequency (Hz) | 2740
Loaded Peak (dB) | 1.35
Inductance Test Resonant Frequency (Hz) | 1100
Inductance Test Capacitance (F) | 4.3E-09
Probe Capacitance (pF) | 10
Test Load Resistance (ohms) | 200000
Calculated Inductance (H) | 4.86840205854016
Calculated Intrinsic Capacitance (F) | 1.23624054898093E-10
Calculated Intrinsic Capacitance (pF) | 123.624054898093
Loaded Parallel Q Calculated from Rs, Rl | 1.75349222989962
Loaded Parallel Q Calculated from Peak | 1.16815372986132
Loaded Peak Loss (dB) | 3.52807691539466
Series Q | 27.184344568182
Calculated Loaded Resonant Frequency (Hz) | 2960.54159609976
Device Circuit under Test | Example Test
Test Date | 42622
Notes | V5.4 box
DC resistance (ohms) | 7300
Self Resonant Frequency (Hz) | 6240
Self Resonant Peak (dB) | 3
Loaded Resonant Frequency (Hz) | 2740
Loaded Peak (dB) | 1.35
Inductance Test Resonant Frequency (Hz) | 1100
Inductance Test Capacitance (F) | 4.3E-09
Probe Capacitance (pF) | 10
Test Load Resistance (ohms) | 200000
Calculated Inductance (H) | 4.86840205854016
Calculated Intrinsic Capacitance (F) | 1.23624054898093E-10
Calculated Intrinsic Capacitance (pF) | 123.624054898093
Loaded Parallel Q Calculated from Rs, Rl | 1.75349222989962
Loaded Parallel Q Calculated from Peak | 1.16815372986132
Loaded Peak Loss (dB) | 3.52807691539466
Series Q | 27.184344568182
Calculated Loaded Resonant Frequency (Hz) | 2960.54159609976
Device Circuit under Test | Example Test
Test Date | 42622
Notes | V5.4 box
DC resistance (ohms) | 7300
Self Resonant Frequency (Hz) | 6240
Self Resonant Peak (dB) | 3
Loaded Resonant Frequency (Hz) | 2740
Loaded Peak (dB) | 1.35
Inductance Test Resonant Frequency (Hz) | 1100
Inductance Test Capacitance (F) | 4.3E-09
Probe Capacitance (pF) | 10
Test Load Resistance (ohms) | 200000
Calculated Inductance (H) | 4.86840205854016
Calculated Intrinsic Capacitance (F) | 1.23624054898093E-10
Calculated Intrinsic Capacitance (pF) | 123.624054898093
Loaded Parallel Q Calculated from Rs, Rl | 1.75349222989962
Loaded Parallel Q Calculated from Peak | 1.16815372986132
Loaded Peak Loss (dB) | 3.52807691539466
Series Q | 27.184344568182
Calculated Loaded Resonant Frequency (Hz) | 2960.54159609976
Device Circuit under Test | Example Test
Test Date | 42622
Notes | V5.4 box
DC resistance (ohms) | 7300
Self Resonant Frequency (Hz) | 6240
Self Resonant Peak (dB) | 3
Loaded Resonant Frequency (Hz) | 2740
Loaded Peak (dB) | 1.35
Inductance Test Resonant Frequency (Hz) | 1100
Inductance Test Capacitance (F) | 4.3E-09
Probe Capacitance (pF) | 10
Test Load Resistance (ohms) | 200000
Calculated Inductance (H) | 4.86840205854016
Calculated Intrinsic Capacitance (F) | 1.23624054898093E-10
Calculated Intrinsic Capacitance (pF) | 123.624054898093
Loaded Parallel Q Calculated from Rs, Rl | 1.75349222989962
Loaded Parallel Q Calculated from Peak | 1.16815372986132
Loaded Peak Loss (dB) | 3.52807691539466
Series Q | 27.184344568182
Calculated Loaded Resonant Frequency (Hz) | 2960.54159609976
Device Circuit under Test | Example Test
Test Date | 42622
Notes | V5.4 box
DC resistance (ohms) | 7300
Self Resonant Frequency (Hz) | 6240
Self Resonant Peak (dB) | 3
Loaded Resonant Frequency (Hz) | 2740
Loaded Peak (dB) | 1.35
Inductance Test Resonant Frequency (Hz) | 1100
Inductance Test Capacitance (F) | 4.3E-09
Probe Capacitance (pF) | 10
Test Load Resistance (ohms) | 200000
Calculated Inductance (H) | 4.86840205854016
Calculated Intrinsic Capacitance (F) | 1.23624054898093E-10
Calculated Intrinsic Capacitance (pF) | 123.624054898093
Loaded Parallel Q Calculated from Rs, Rl | 1.75349222989962
Loaded Parallel Q Calculated from Peak | 1.16815372986132
Loaded Peak Loss (dB) | 3.52807691539466
Series Q | 27.184344568182
Calculated Loaded Resonant Frequency (Hz) | 2960.54159609976
Device Circuit under Test | Example Test
Test Date | 42622
Notes | V5.4 box
DC resistance (ohms) | 7300
Self Resonant Frequency (Hz) | 6240
Self Resonant Peak (dB) | 3
Loaded Resonant Frequency (Hz) | 2740
Loaded Peak (dB) | 1.35
Inductance Test Resonant Frequency (Hz) | 1100
Inductance Test Capacitance (F) | 4.3E-09
Probe Capacitance (pF) | 10
Test Load Resistance (ohms) | 200000
Calculated Inductance (H) | 4.86840205854016
Calculated Intrinsic Capacitance (F) | 1.23624054898093E-10
Calculated Intrinsic Capacitance (pF) | 123.624054898093
Loaded Parallel Q Calculated from Rs, Rl | 1.75349222989962
Loaded Parallel Q Calculated from Peak | 1.16815372986132
Loaded Peak Loss (dB) | 3.52807691539466
Series Q | 27.184344568182
Calculated Loaded Resonant Frequency (Hz) | 2960.54159609976
Device Circuit under Test | Example Test
Test Date | 42622
Notes | V5.4 box
DC resistance (ohms) | 7300
Self Resonant Frequency (Hz) | 6240
Self Resonant Peak (dB) | 3
Loaded Resonant Frequency (Hz) | 2740
Loaded Peak (dB) | 1.35
Inductance Test Resonant Frequency (Hz) | 1100
Inductance Test Capacitance (F) | 4.3E-09
Probe Capacitance (pF) | 10
Test Load Resistance (ohms) | 200000
Calculated Inductance (H) | 4.86840205854016
Calculated Intrinsic Capacitance (F) | 1.23624054898093E-10
Calculated Intrinsic Capacitance (pF) | 123.624054898093
Loaded Parallel Q Calculated from Rs, Rl | 1.75349222989962
Loaded Parallel Q Calculated from Peak | 1.16815372986132
Loaded Peak Loss (dB) | 3.52807691539466
Series Q | 27.184344568182
Calculated Loaded Resonant Frequency (Hz) | 2960.54159609976
Device Circuit under Test | Example Test
Test Date | 42622
Notes | V5.4 box
DC resistance (ohms) | 7300
Self Resonant Frequency (Hz) | 6240
Self Resonant Peak (dB) | 3
Loaded Resonant Frequency (Hz) | 2740
Loaded Peak (dB) | 1.35
Inductance Test Resonant Frequency (Hz) | 1100
Inductance Test Capacitance (F) | 4.3E-09
Probe Capacitance (pF) | 10
Test Load Resistance (ohms) | 200000
Calculated Inductance (H) | 4.86840205854016
Calculated Intrinsic Capacitance (F) | 1.23624054898093E-10
Calculated Intrinsic Capacitance (pF) | 123.624054898093
Loaded Parallel Q Calculated from Rs, Rl | 1.75349222989962
Loaded Parallel Q Calculated from Peak | 1.16815372986132
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

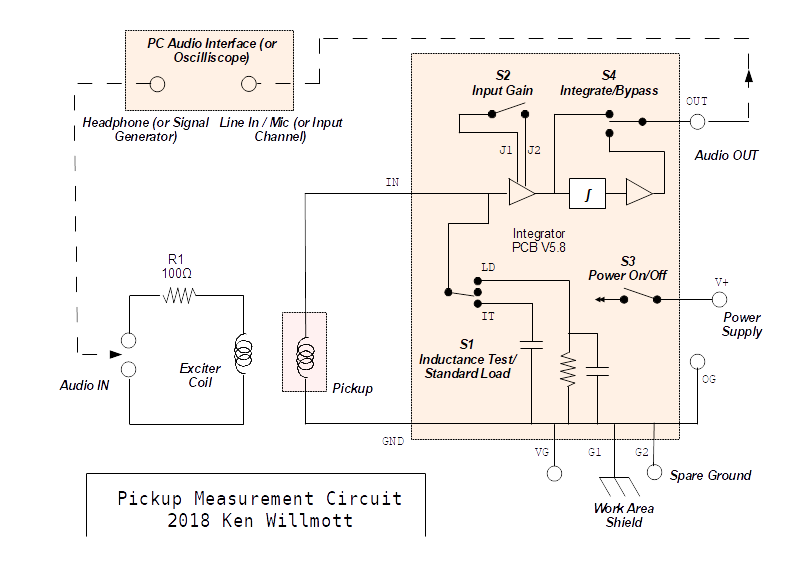
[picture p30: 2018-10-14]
advanced_measurement_3.png

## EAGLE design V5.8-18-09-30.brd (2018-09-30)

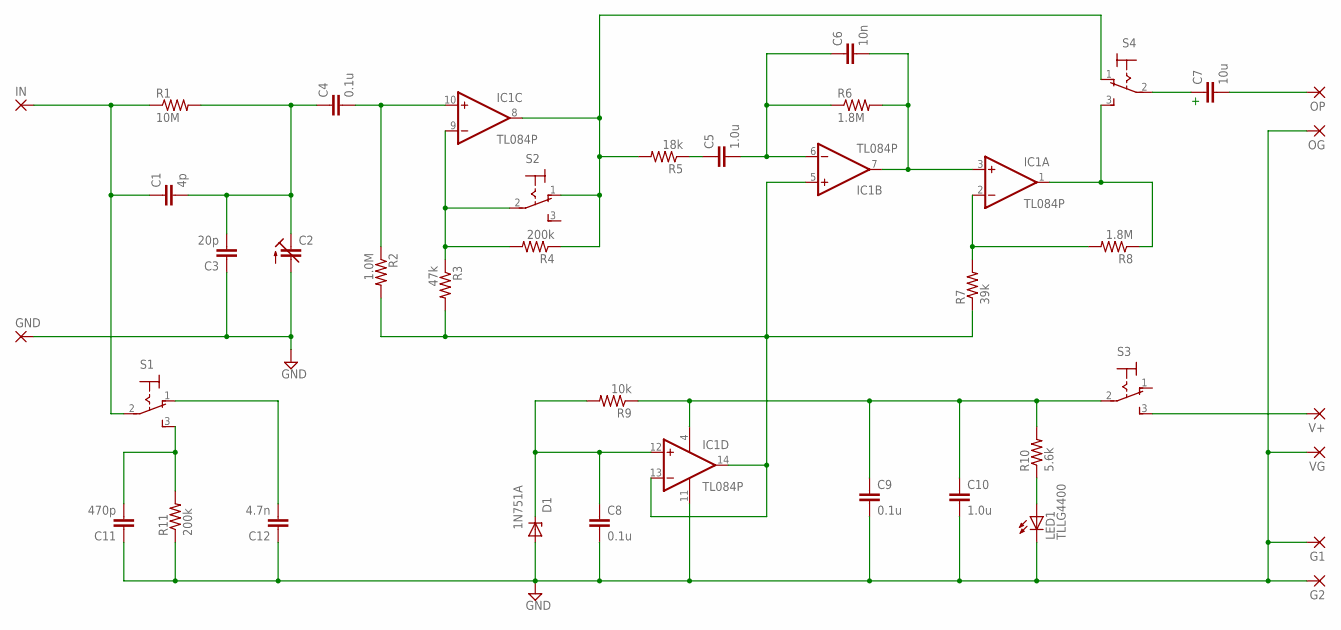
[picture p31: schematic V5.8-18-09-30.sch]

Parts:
C1: 4p; C050-024X044
C2: C-TRIMMGKG20015; GKG20015
C3: 20p; C050-024X044
C4, C8, C9: 0.1u; C050-024X044
C5, C10: 1.0u; C050-024X044
C6: 10n; C050-024X044
C7: 10u; C050-024X044
C11: 470p; C050-024X044
C12: 4.7n; C050-024X044
D1: ZENER-DIODEDO35Z10; DO35Z10
G1, G2: 2,54/1,1
GND: 2,54/1,1
IC1: TL084P; DIL14
IN: 2,54/1,1
LED1: TLLG4400; LED3MM
OG: 2,54/1,1
OP: 2,54/1,1
R1: 10M; 0207/10
R2: 1.0M; 0207/10
R3: 47k; 0207/10
R4, R11: 200k; 0207/10
R5: 18k; 0207/10
R6, R8: 1.8M; 0207/10
R7: 39k; 0207/10
R9: 10k; 0207/10
R10: 5.6k; 0207/10
S1, S2, S3, S4: 320-916
V+: 2,54/1,1
VG: 2,54/1,1

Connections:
GND: C2.1 (A), C3.1, C8.2, C9.2, C10.2, C11.1, C12.1, D1.A, G1.1, G2.1, GND.1, IC1.11 (V-), LED1.K (C), OG.1, R11.1, VG.1
IT: C12.2, S1.1 (O)
unnamed: LED1.A, R10.1
unnamed: C5.1, R5.1
unnamed: S3.3 (S), V+.1
unnamed: IC1.8 (OUT), R4.1, R5.2, S2.1 (O), S4.1 (O)
unnamed: IC1.9 (-IN), R3.1, R4.2, S2.2
unnamed: C6.2, IC1.3 (+IN), IC1.7 (OUT), R6.2
unnamed: IC1.2 (-IN), R7.2, R8.2
unnamed: IC1.1 (OUT), R8.1, S4.3 (S)
unnamed: C1.2, C2.2 (E), C3.2, C4.1, R1.2
unnamed: C8.1, D1.C, IC1.12 (+IN), R9.2
unnamed: C4.2, IC1.10 (+IN), R2.1
unnamed: C1.1, IN.1, R1.1, S1.2
unnamed: IC1.5 (+IN), IC1.13 (-IN), IC1.14 (OUT), R2.2, R3.2, R7.1
unnamed: C9.1, C10.1, IC1.4 (V+), R9.1, R10.2, S3.2
unnamed: C11.2, R11.2, S1.3 (S)
unnamed: C7.1, S4.2
unnamed: C5.2, C6.1, IC1.6 (-IN), R6.1
unnamed: C7.2, OP.1

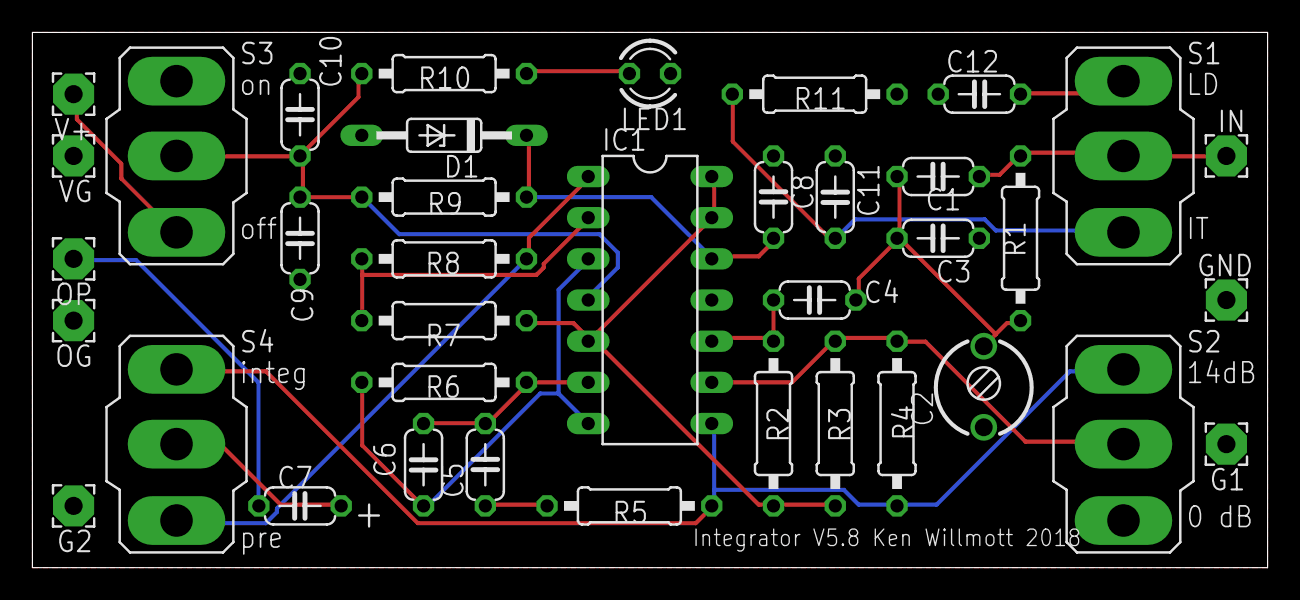
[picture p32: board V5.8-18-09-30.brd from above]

Board: 2 copper layers, 76.2 x 33.0 mm, 38 parts (0 on the bottom side), 20 nets.

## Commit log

2018-09-29 fix incorrect screen for preamp gain label
    [V5.8-18-09-27.brd]
2018-09-30 Add files via upload
    Corrected switch and trim cap dimensions and made board smaller
    [V5.8-18-09-30.brd, V5.8-18-09-30.sch]
2018-10-06 completed for supplier Mouser Inc.
    [V5.8-BOM.ods]
2018-10-14 add gerbers
2018-10-15 spreadsheet for results analysis
    [test log template 2018-10.ods]
2019-06-17 update BOM to reflect component changes on PCB
    [V5.8-BOM.ods]
2019-07-08 correct errors in Mouser part numbers
    [V5.8-BOM.ods]
2019-07-15 add device assembly guide
2019-07-27 updating schematic
2019-07-27 updating values to match BOM
2019-07-27 update values to match BOM
2019-08-19 replace C7 tantalum with MLCC and add cap markings
    [V5.8-BOM.ods]
2020-05-18 minor updates to BOM
    change C10 from 1.0uF to 10uF
    [V5.9-BOM.ods]
